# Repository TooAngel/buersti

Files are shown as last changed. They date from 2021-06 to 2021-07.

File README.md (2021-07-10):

# Buersti

Have a look at https://emanual.robotis.com/docs/en/platform/turtlebot3/overview/

## Circuit

- Resistor before LED: Reduce current (https://www.build-electronic-circuits.com/resistor-before-or-after-led/)
- Capacitor at power supply: Preventing voltage spikes?
  - The power supply consists of the electrolytic
capacitor C1 that smoothes the supply voltage (which is very important because the 3 DC motors are
all operated with PWM) 
  - (https://www.quora.com/Capacitors-block-DC-voltage-Why-they-are-used-in-DC-circuits?share=1)
- voltage divider
  - https://en.wikipedia.org/wiki/Voltage_divider

## TODO

- motor holder positions wrong
- motor screws wrong
- thread holes to big (wheel_connector)
- wheels have a bad tracktion
- the chassis should be thicker
- better brush
- brush motor faster
- remove arduino, rapsberry pi should be enough

## To buy

- Akku connector
- m3 nuts
- 2er schraubdinger
- 3er schraubdinger
- 12Vto5V raspberry pi & lidar wandler
- usb FTDI-Adapter for lidar
- Schalter
- gummi Abstandshalter
- m3 nuts?

## Motor driver

- https://components101.com/modules/l293n-motor-driver-module
- https://www.electronicshub.org/raspberry-pi-l298n-interface-tutorial-control-dc-motor-l298n-raspberry-pi/

## LIDAR

- http://www.core-tec.co.uk/BadPidea/uncategorized/lidar-on-the-cheap-using-the-hls-lfcd2-pt2/
- https://mein-roboter.blogspot.com/2020/01/lidar-loppt_15.html
- http://wiki.ros.org/hls_lfcd_lds_driver
- https://emanual.robotis.com/assets/docs/LDS_Basic_Specification.pdf

## Raspberry PI setup

- Install python
- Install evdev and serial

### Motors

- https://www.conrad.de/de/p/modelcraft-rb350200-0a101r-getriebemotor-12-v-1-200-227579.html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

Maybe this?
https://www.conrad.de/de/p/motraxx-gleichstrommotor-sr555shp-3247s-75-sr555shp-3247s-75-12-0-v-dc-1-463-a-25-18-nmm-5028-u-min-wellen-durchmesser-1711504.html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
or this?
https://www.amazon.com/PLUMIA-Eccentric-Diameter-Electric-Reduction/dp/B08YR9WZ26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

Copy init script sudo cp /home/pi/gamecontroller /etc/init.d
Register script sudo update-rc.d gamecontroller defaults

## How to set it up

- Plug stuff together
- deploy arduino files to the arduino
- copy gamecontroller.py to raspberry pi
- use the init script somehow on the raspberry pi

### Inspired by

http://reprap-windturbine.com/index.php?id=20&L=1

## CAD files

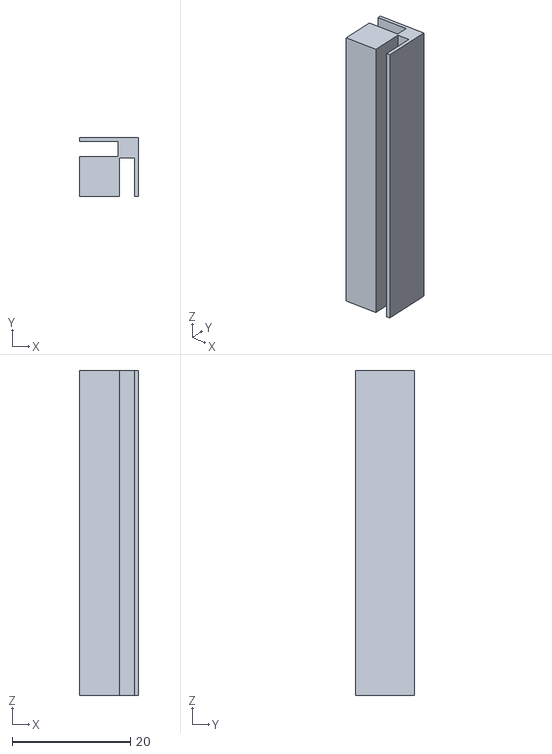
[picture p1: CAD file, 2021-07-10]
sideEdges.stl
10.0 x 10.0 x 55.0

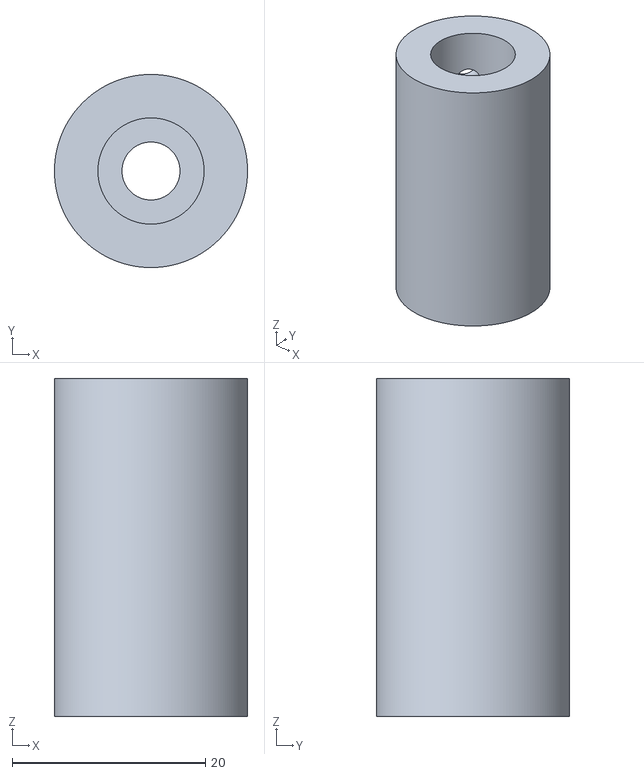
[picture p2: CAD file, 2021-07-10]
brushConnector.stl
20.0 x 20.0 x 35.0

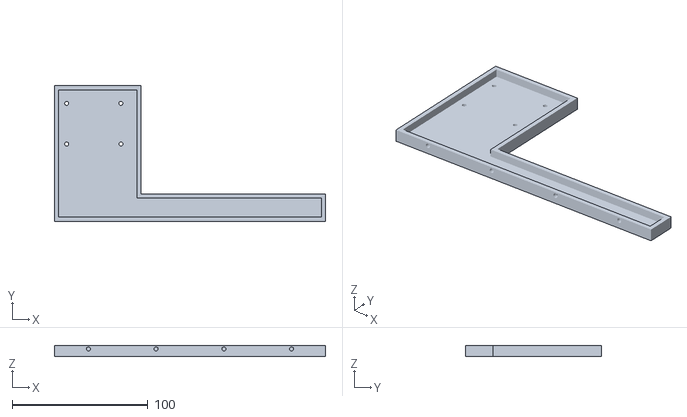
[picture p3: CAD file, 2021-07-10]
frontplate.stl
200.0 x 100.0 x 8.00

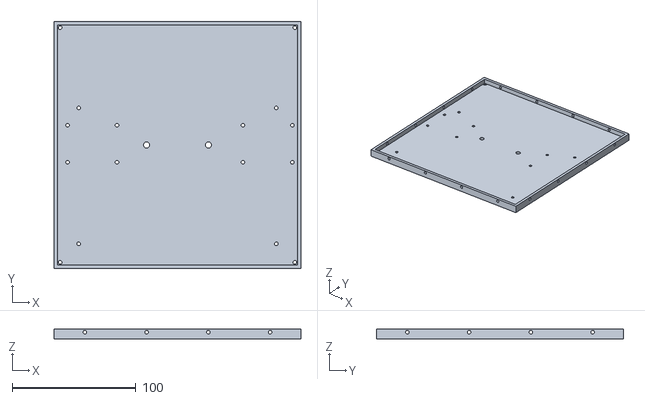
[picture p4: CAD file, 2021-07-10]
backplate.stl
200.0 x 200.0 x 8.00

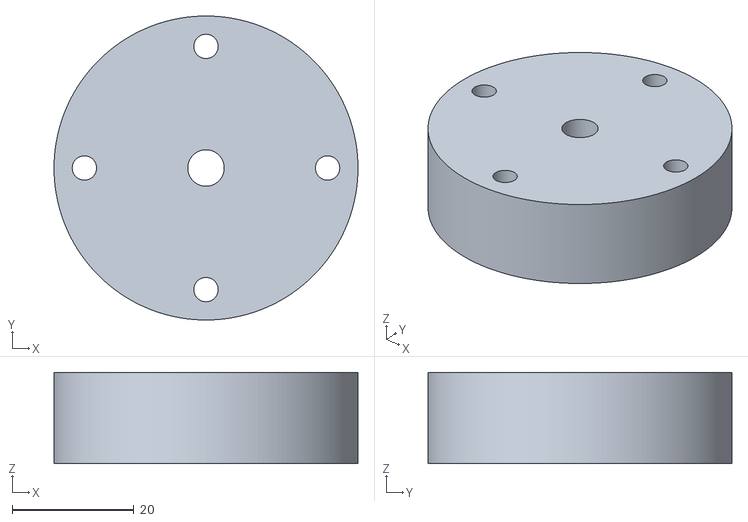
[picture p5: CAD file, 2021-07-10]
wheels_connector.stl
50.0 x 50.0 x 15.0

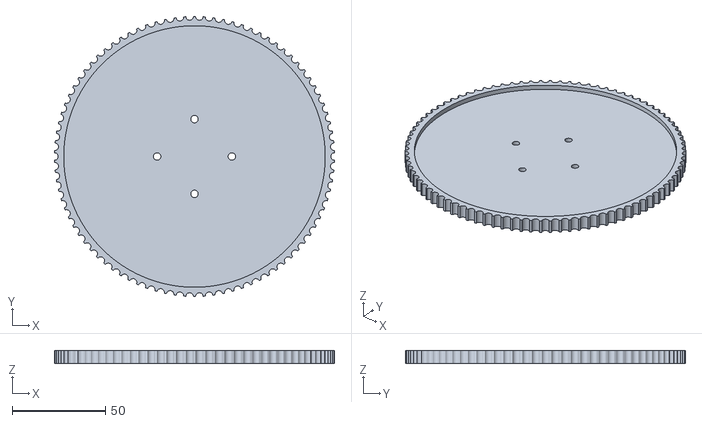
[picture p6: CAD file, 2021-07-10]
wheel.stl
149.9 x 150.0 x 7.00

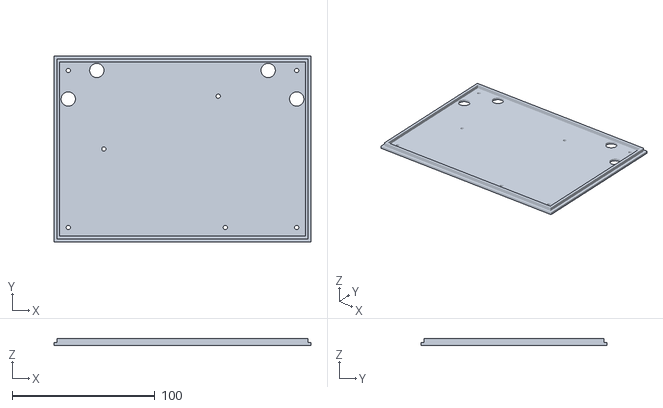
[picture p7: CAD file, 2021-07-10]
electronic.stl
180.0 x 130.0 x 5.00

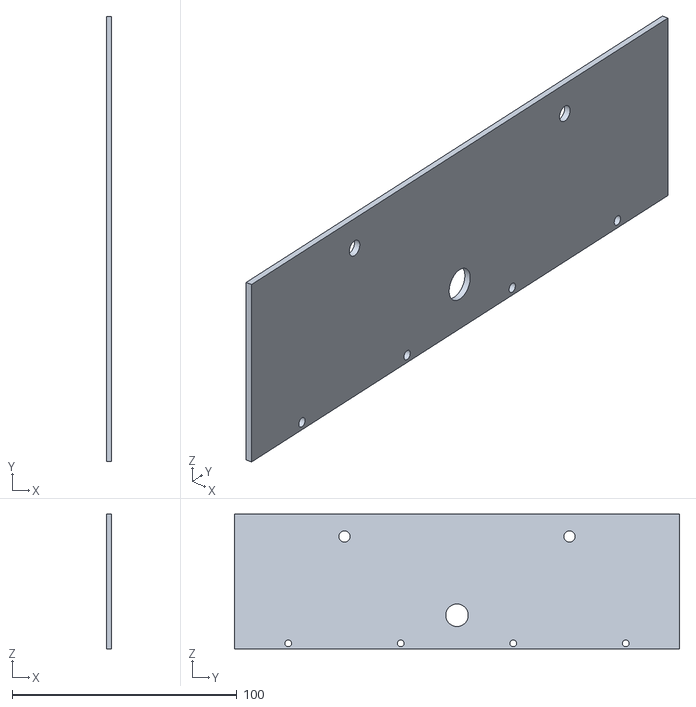
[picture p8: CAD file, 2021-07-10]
side.stl
2.00 x 198.0 x 60.0

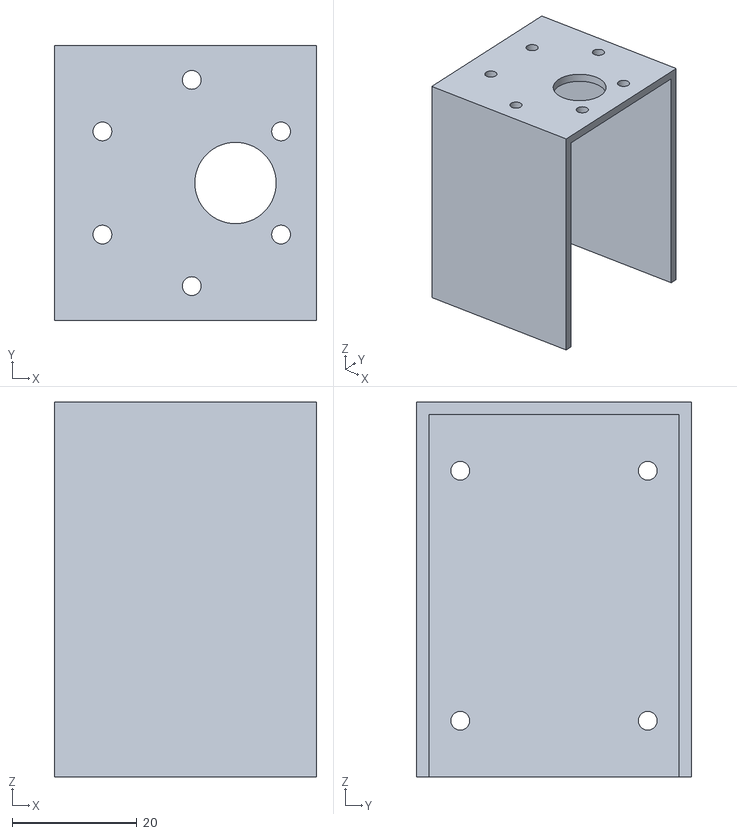
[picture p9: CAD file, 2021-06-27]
motorHolder.stl
42.0 x 44.0 x 60.0

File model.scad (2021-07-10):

include <libraries/OpenSCAD-Arduino-Mounting-Library/arduino.scad>


thickness = 10;

width = 200;
depth = 300;

wheel_diameter = 100;
wheel_y_offset = wheel_diameter / 2 + 50;
wheel_z_offset = -28;

brush_holder_x_offset = 10;
brush_holder_y_offset = 10;

brush_diameter_inner = 25;
brush_diameter = 80;
brush_length = 80;

$fn = 180;

module motorR835() {
    // https://asset.conrad.com/media10/add/160267/c1/-/en/000227579DS01/datenblatt-227579-modelcraft-rb350200-0a101r-getriebemotor-12-v-1200.pdf
    color("lightgrey", 1.0) {
        back_diameter = 35;
        back_height = 29;
        
        middle_diameter = 37;
        middle_height = 27;
        
        front_diameter = 12;
        front_height = 7;
        front_offset = 7;
        
        turning_diameter = 6;
        turning_height = 15;
        
        screw_diameter = 3; // 6~M3xp0.5
        screw_height = 6; // ???
        
        cylinder(d=back_diameter, back_height);
        translate([0, 0, back_height]) difference() {
             cylinder(d=middle_diameter, middle_height);
            // screw holes
            rotate([0, 0, 30]) translate([middle_diameter / 2 - 0.5 - screw_diameter / 2, 0, middle_height - screw_height]) cylinder(d=screw_diameter, screw_height);
            rotate([0, 0, -30]) translate([middle_diameter / 2 - 0.5 - screw_diameter / 2, 0, middle_height - screw_height]) cylinder(d=screw_diameter, screw_height);
            rotate([0, 0, 90]) translate([middle_diameter / 2 - 0.5 - screw_diameter / 2, 0, middle_height - screw_height]) cylinder(d=screw_diameter, screw_height);           
            rotate([0, 0, -90]) translate([middle_diameter / 2 - 0.5 - screw_diameter / 2, 0, middle_height - screw_height]) cylinder(d=screw_diameter, screw_height);
            rotate([0, 0, 150]) translate([middle_diameter / 2 - 0.5 - screw_diameter / 2, 0, middle_height - screw_height]) cylinder(d=screw_diameter, screw_height);
            rotate([0, 0, -150]) translate([middle_diameter / 2 - 0.5 - screw_diameter / 2, 0, middle_height - screw_height]) cylinder(d=screw_diameter, screw_height);
        }
        
        translate([front_offset, 0, back_height + middle_height]) cylinder(d=front_diameter, front_height);
        
        translate([front_offset, 0, back_height + middle_height + front_height]) cylinder(d=turning_diameter, turning_height);
    }
}


module motorHolder() {
    translate([width / 2 + thickness, depth / 2 + thickness, 0]) motorR835();
    
    thickness = 2;
    width = 40;
    depth = 40;
    height = 58;
    
    middle_diameter = 37;
    middle_height = 27;
    
    front_diameter = 12 + 1;
    front_offset = 7;
           
    screw_diameter = 3; // 6~M3xp0.5
    screw_height = 6; // ???
    
    base_plate_screw_distance_y = 30;
    base_plate_screw_distance_z = 40;

    color("blue", 0.8) {
        difference() {
            cube([width + thickness, depth + 2 * thickness, height + thickness]);
            translate([thickness, thickness, 0]) cube([width, depth, height]);
            
            translate([width / 2 + thickness, depth / 2 + thickness, height]) {
                // screw holes
                rotate([0, 0, 30]) translate([middle_diameter / 2 - 0.5 - screw_diameter / 2, 0, 0]) cylinder(d=screw_diameter, thickness);
                rotate([0, 0, -30]) translate([middle_diameter / 2 - 0.5 - screw_diameter / 2, 0, 0]) cylinder(d=screw_diameter, thickness);
                rotate([0, 0, 90]) translate([middle_diameter / 2 - 0.5 - screw_diameter / 2, 0, 0]) cylinder(d=screw_diameter, thickness);           
                rotate([0, 0, -90]) translate([middle_diameter / 2 - 0.5 - screw_diameter / 2, 0, 0]) cylinder(d=screw_diameter, thickness);
                rotate([0, 0, 150]) translate([middle_diameter / 2 - 0.5 - screw_diameter / 2, 0, 0]) cylinder(d=screw_diameter, thickness);
                rotate([0, 0, -150]) translate([middle_diameter / 2 - 0.5 - screw_diameter / 2, 0, 0]) cylinder(d=screw_diameter, thickness);
            }
        
            // motor axis
            translate([width / 2 + thickness + front_offset, depth / 2 + thickness, height]) cylinder(d=front_diameter, thickness);
            
            // base plate screws
            translate([0, (depth - base_plate_screw_distance_y) / 2 + thickness, (height - base_plate_screw_distance_z) / 2]) rotate([0, 90, 0]) cylinder(d=3, 5);
            translate([0, (depth - base_plate_screw_distance_y) / 2 + thickness + base_plate_screw_distance_y, (height - base_plate_screw_distance_z) / 2]) rotate([0, 90, 0]) cylinder(d=3, 5);
            translate([0, (depth - base_plate_screw_distance_y) / 2 + thickness, (height - base_plate_screw_distance_z) / 2 + base_plate_screw_distance_z]) rotate([0, 90, 0]) cylinder(d=3, 5);
            translate([0, (depth - base_plate_screw_distance_y) / 2 + thickness + base_plate_screw_distance_y, (height - base_plate_screw_distance_z) / 2 + base_plate_screw_distance_z]) rotate([0, 90, 0]) cylinder(d=3, 5);
        }
    }
}
//motorHolder();


module brush() {
    color("white", 0.4) {
        cylinder(d=brush_diameter_inner, brush_length);
        for ( z_offset = [0: brush_length/10: brush_length]) {
            for ( z_rotate = [0:10:360]) {
                translate([0, 0, z_offset]) rotate([0, 0, z_rotate]) translate([0, -0.5, 0]) cube([brush_diameter / 2, 1, 1]);
            }
        }
    }
}

module brushConnector() {
    diameter = 20;
    hole_diameter = 6;
    motor_axis_length = 15;
    
    screw_diameter = 3.3;
    screw_offset = 20;
    
    brush_inner_diameter = 11;
    brush_length = 20;
    
    
    difference() {
        cylinder(d=diameter, motor_axis_length, center=true);
        cylinder(d=hole_diameter, motor_axis_length, center=true);

        // motor connector screw
        translate([-diameter/3, diameter/3, 0]) rotate([90, 0, 45]) cylinder(d=screw_diameter, diameter, center=true);
    }
    
    translate([0, 0, motor_axis_length / 2 + brush_length / 2]) difference() {
        cylinder(d=diameter, brush_length, center=true);
        cylinder(d=brush_inner_diameter, brush_length, center=true);
        // motor connector screw
        translate([-diameter/3, diameter/3, 3]) rotate([90, 0, 45]) cylinder(d=screw_diameter, diameter, center=true);
    }
}
//brushConnector();

module side() {
    width = 2;
    depth = 198;
    height = 60;
    connect_holes_diameter = 3;
    led_diameter = 5;
    cable_diameter = 10;
    
    difference() {
        translate([0, 1, 0]) cube([width, depth, height]);
        
        // mount holes
        translate([0, 25, connect_holes_diameter / 2 + 1]) rotate([0, 90, 0]) cylinder(d=connect_holes_diameter, width);
        translate([0, 75, connect_holes_diameter / 2 + 1]) rotate([0, 90, 0]) cylinder(d=connect_holes_diameter, width);
        translate([0, 125, connect_holes_diameter / 2 + 1]) rotate([0, 90, 0]) cylinder(d=connect_holes_diameter, width);
        translate([0, 175, connect_holes_diameter / 2 + 1]) rotate([0, 90, 0]) cylinder(d=connect_holes_diameter, width);
        
        // leds
        translate([0, 50, 50]) rotate([0, 90, 0]) cylinder(d=led_diameter, width);
        translate([0, 150, 50]) rotate([0, 90, 0]) cylinder(d=led_diameter, width);
        
        // cable hole
        translate([0, 100, 15]) rotate([0, 90, 0]) cylinder(d=cable_diameter, width);
    }
}

//side();

module sideEdges() {
    difference() {
        cube([10, 10, 55]);
        translate([6.8, 0, 0]) cube([2.5, 6.5, 55]);
        translate([0, 6.8, 0]) cube([6.5, 2.5, 55]);
    }
}
//sideEdges();
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

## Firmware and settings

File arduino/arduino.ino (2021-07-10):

int voltpin = 0; // A0 for battery voltage

float voltAverageRaw; // Value for average voltage
float voltAverage; // Calculated value for average voltage
float VOLTLOW = 10; // Low voltage

int redled = 12;
int greenled = 13;

int driveleftpwmpin = 9;
int driveleft0pin = 6;
int driveleft1pin = 5;

int driverightpwmpin = 10;
int driveright0pin = 8;
int driveright1pin = 7;

int driveleftspeed = 0; // 160; // 255;
int driverightspeed = 0; // 160; // 255;


int brushpin = 11;
int brushSpeed = 0; //; // Max 255

int greenLight = 1;
int redLight = 1;

void setup() {
  Serial.begin(57600);

  pinMode(driveleft0pin, OUTPUT);
  pinMode(driveleft1pin, OUTPUT);
  pinMode(driveright0pin, OUTPUT);
  pinMode(driveright1pin, OUTPUT);

  pinMode(redled, OUTPUT);
  pinMode(greenled, OUTPUT);
  digitalWrite(redled, HIGH);
  
  voltAverageRaw = analogRead(voltpin);
  voltAverage = voltAverageRaw * 5.0 / 1023 * 26.7 / 4.7; // is factor for voltagedevider 22K / 4,7K

}

bool isStopped() {
  if (voltAverage < VOLTLOW) {
    Serial.print("STOPPED: ");
    Serial.println(voltAverage);
    return true;
  }
  
  float voltRaw = analogRead(voltpin);
  voltAverageRaw = 0.9 * voltAverageRaw + 0.1 * voltRaw;
  Serial.print("Raw volt value: ");
  Serial.println(voltRaw);
  Serial.print("Average raw volt value: ");
  Serial.println(voltAverageRaw);
  voltAverage = voltAverageRaw * 5.0 / 1023 * 26.7 / 4.7; // is factor for voltagedevider 22K / 4,7K
  
  Serial.print("Calculated volt value: ");
  Serial.println(voltAverage);
  Serial.println("");
  return false;
}

void drive()  {
  if (driveleftspeed > 0) {
    digitalWrite(driveleft0pin, LOW);
    digitalWrite(driveleft1pin, HIGH);
    analogWrite(driveleftpwmpin, driveleftspeed);
  } else {
    digitalWrite(driveleft0pin, HIGH);
    digitalWrite(driveleft1pin, LOW);
    analogWrite(driveleftpwmpin, -1 * driveleftspeed);
  }

  if (driverightspeed > 0) {
    digitalWrite(driveright0pin, LOW);
    digitalWrite(driveright1pin, HIGH);
    analogWrite(driverightpwmpin, driverightspeed);
  } else {
    
    digitalWrite(driveright0pin, HIGH);
    digitalWrite(driveright1pin, LOW);
    analogWrite(driverightpwmpin, -1 * driverightspeed);
  }
}

bool readFromSerial() {
  if (Serial.available() > 0) {
    String data = Serial.readStringUntil('\n');
    Serial.print("You sent me: ");
    Serial.println(data);
    int firstSpace = data.indexOf(' ');
    int left = data.substring(0, firstSpace).toInt();
    int secondSpace = data.indexOf(' ', firstSpace + 1);
    int right = data.substring(firstSpace + 1, secondSpace).toInt();
    int thirdSpace = data.indexOf(' ', secondSpace + 1);
    int brush = data.substring(secondSpace + 1, thirdSpace).toInt();
    int fourthSpace = data.indexOf(' ', thirdSpace + 1);
    int green = data.substring(thirdSpace + 1, fourthSpace).toInt();
    int red = data.substring(fourthSpace + 1).toInt();
    
    driveleftspeed = min(left, 220);
    driverightspeed = min(right, 220);
    brushSpeed = min(brush, 200);
    greenLight = min(green, 1);
    redLight = min(red, 1);
    return true;
  }
  return false;
}

void loop() {
  if (isStopped()) {
    readFromSerial();
    delay(1000);
    return;
  }

  if (readFromSerial()) {
    drive();
    analogWrite(brushpin, brushSpeed);
    digitalWrite(redled, redLight == 1 ? HIGH : LOW);
    digitalWrite(greenled, greenLight == 1 ? HIGH : LOW);
  }
}

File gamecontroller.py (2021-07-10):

from evdev import InputDevice, InputEvent
import math
import serial
import time
import threading
import os
import sys
import logging
import logging.handlers

logger = logging.getLogger(__name__)
logger.setLevel(logging.DEBUG)

handler = logging.handlers.SysLogHandler(address='/dev/log')
handler.setLevel(logging.DEBUG)
logger.addHandler(handler)

consoleHandler = logging.StreamHandler(sys.stdout)
consoleHandler.setLevel(logging.DEBUG)
logger.addHandler(consoleHandler)

pid = str(os.getpid())
f = open('gamecontroller.pid', 'w')
f.write(pid)
f.close()

class Controller(threading.Thread):
    def __init__(self):
        threading.Thread.__init__(self)
        self.values = {
            'left': 0,
            'right': 0,
            'brush': 0,
            'green': 1,
            'red': 1,
        }
        self.running = True
    
    def setValue(self, key, value):
        if self.values[key] != value:
            self.values[key] = value
            toSend = '{} {} {} {} {}'.format(
                self.values['left'],
                self.values['right'],
                self.values['brush'],
                self.values['green'],
                self.values['red'])
            logger.info('Sending: {}'.format(toSend))
            self.arduino.write('{}\n'.format(toSend))

    def run(self):
        # TODO get the correct device
        self.gamepad = InputDevice('/dev/input/event2')
        
        left_code = 1
        right_code = 4
        brush_code = 5
        green = 304
        red = 305

        max_value = 32687.
        max_brush_value = 255.

        for event in self.gamepad.read_loop():
            if not self.running:
                return

            if event.code == 0:
                continue # Skip for some reason, not sure what it is

            if event.code == left_code:
                self.setValue('left', int(math.floor(-1 * event.value / max_value * 200)))
                continue

            if event.code == right_code:
                self.setValue('right', int(math.floor(-1 * event.value / max_value * 200)))
                continue
            
            if event.code == brush_code:
                self.setValue('brush', int(math.floor(event.value / max_brush_value * 200)))
                continue
            
            if event.code == green:
                if event.value == 1:
                    self.setValue('green', int(not self.values['green']))
                continue

            if event.code == red:
                if event.value == 1:
                    self.setValue('red', int(not self.values['red']))
                continue

            logger.info(event)

class Reader(threading.Thread):
    def __init__(self):
        threading.Thread.__init__(self)
        self.running = True

    def run(self):
         while self.running:
            line = self.arduino.readline().decode('utf-8').rstrip()
            logger.info(line)

def main():
    controller = Controller()
    reader = Reader()
    try:
        arduino = serial.Serial('/dev/ttyACM0', 57600, timeout=1)
        controller.arduino = arduino
        controller.start()
        reader.arduino = arduino
        reader.start()

        while True:
            time.sleep(1)

    except KeyboardInterrupt:
        logger.info('KeyboardInterrupt')
        controller.running = False
        # controller.gamepad.write_event(InputEvent(0, 0, 0, 0, 0))
        reader.running = False


if __name__ == '__main__':
    main()

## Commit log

2021-06-27 Initial models and kicad stuff
    [kicad.kicad_pcb, kicad.sch, model.scad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]
2021-07-10 Buersti first version
    Model prepared, small fixes were necessary
    Arduino runs somehow
    Raspberry Pi same
    [backplate.stl, brushConnector.stl, electronic.stl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]
